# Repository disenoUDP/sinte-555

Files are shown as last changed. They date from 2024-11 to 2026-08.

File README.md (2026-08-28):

# sinte-555

proyecto inspirado en el chip 555 y el proyecto Atari Punk Console, en su iteración de Oskitone.

## acerca de

proyecto de investigación empezado en 2024, con el objetivo de crear un sintetizador de audio en diseño UDP.

## estructura del repositorio

* [openscad/](./openscad/): archivos de diseño de superficie en openscad
* [kicad/](./kicad/): archivos de diseño de circuito en KiCad

## código

### scripts de automatización

un aspecto muy bello de generar estructuras con STLs a partir de líneas de código, es que el diseño se puede parametrizar y automatizar.

## referencias

* Oskitone <https://oskitone.com>
* How to Create a Shell Script in linux <https://www.geeksforgeeks.org/how-to-create-a-shell-script-in-linux/>
* 555 timer circuits <https://www.555-timer-circuits.com/>

en este taller de 2 horas vamos a aprender a armar un sintetizador conocido como Atari Punk Console (APC).

## lista de materiales (bom)

| Nombre | Cantidad | $ unidad  | Enlace |
| :--- | :--- | :--- | :--- |
| Protoboard | 1 | 1.500 CLP | <https://afel.cl/products/mini-protoboard-400-puntos> |
| Chip 555 | 2 | 400 CLP | <https://www.mechatronicstore.cl/n555-timers/> |
| Potenciómetro 470k | 2 | 490 CLP | <https://www.mechatronicstore.cl/potenciometro-rotacional-10k/> |
| Resistor 10k | 2 | 100 CLP | <https://www.mechatronicstore.cl/resistencia/> |
| Capacitor 100n | 3 | 100 CLP | <https://www.mechatronicstore.cl/condensadores-ceramicos-distintos-valores/> |
| Capacitor 10n | 1 | 100 CLP | <https://www.mechatronicstore.cl/condensadores-ceramicos-distintos-valores/> |
| Parlante | 1 | 3.000 CLP | <https://afel.cl/products/mini-parlante-altavoz-de-3w> |

Algunas tiendas consultadas:

<https://www.mechatronicstore.cl/>
<https://www.victronics.cl/>
<https://www.cabezacuadrada.cl/>

## paso 01: ubicar los chips en la protoboard

tomar la protoboard y conectar los dos chips 555 en ella.

orientar los chips de manera que el pin 1 quede en la esquina inferior izquierda.

el izquierdo recibe el nombre 555-1, el derecho 555-2.

lo mismo con los potenciómetros: a la izquierda pote-1 y a la derecha  pote-2.

## paso 02: conectar la alimentación de los chips

conectar los pines de alimentación de los chips a los rieles de alimentación de la protoboard.

usar cables rojos para conectar al voltaje positivo.

usar cables negros o café para conectar al voltaje negativo (tierra).

## paso 03: armar el circuito de chip 555 de la izquierda, modo astable

patitas de 555-1:

* 1: a GND
* 2: a GND por C de 10n, a patita 3 de pote-1
* 3: a patita 2 de 555-2
* 4: a VCC
* 5: a GND por C de 100n
* 6: a patita 2
* 7: a VCC por R 10k, a patita 2 de pote-1
* 8: a VCC

patitas de pote-1:

* 1: nada
* 2: patita 7 de 555-1
* 3: patita 2 de 555-1

## paso 04: armar el circuito de 555 de la derecha, modo monostable

patitas de 555-2:

* 1: a GND
* 2: a patita 3 del chip 555-1
* 3: a patita 1 de parlante
* 4: a VCC
* 5: a GND por C de 100n
* 6: a patita 3 de pote-2 por R de 10k, a GND por C polarizado de 100n
* 7: a patita 6
* 8: a VCC

patitas de pote-2:

* 1: nada
* 2: a VCC
* 3: a patita 6 de 555-2 por R de 10k

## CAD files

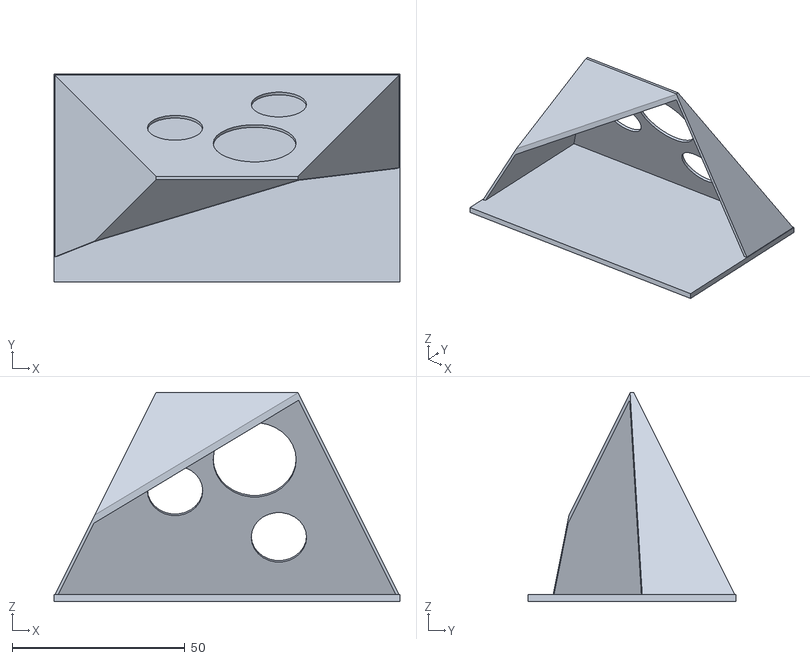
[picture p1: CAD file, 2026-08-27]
stl/piramidev20241211.stl
100.0 x 60.0 x 60.5

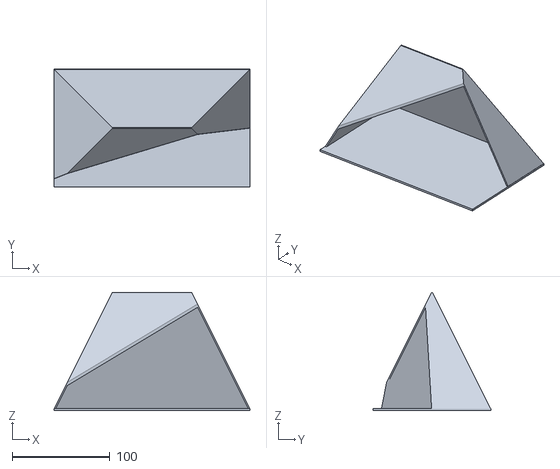
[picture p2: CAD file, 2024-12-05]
stl/piramidev3.stl
200.0 x 120.0 x 120.5

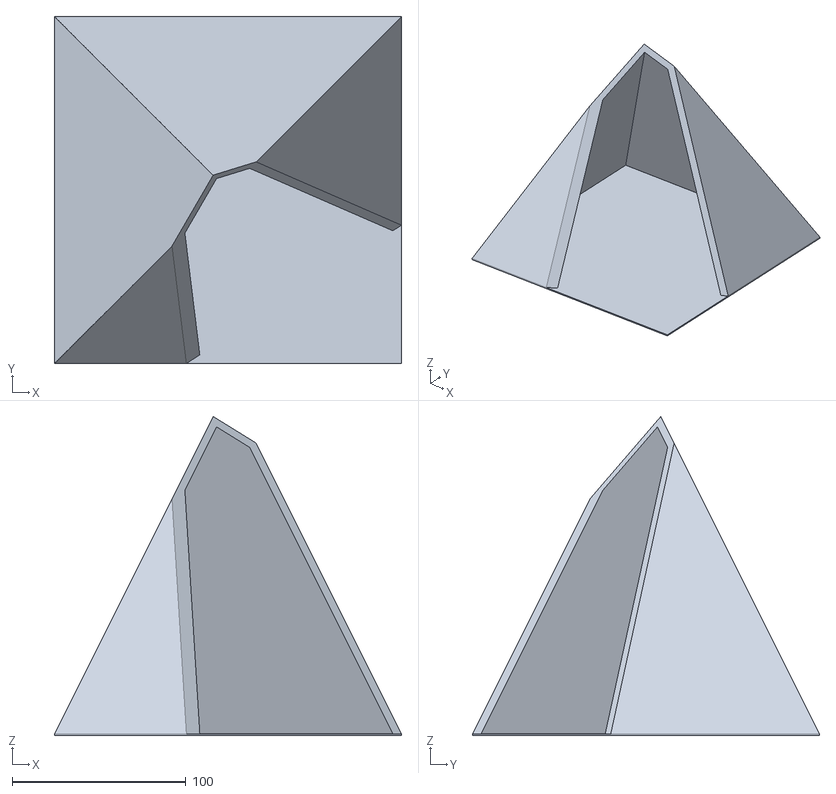
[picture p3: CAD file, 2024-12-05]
stl/piramidev1.stl
200.0 x 200.0 x 183.9

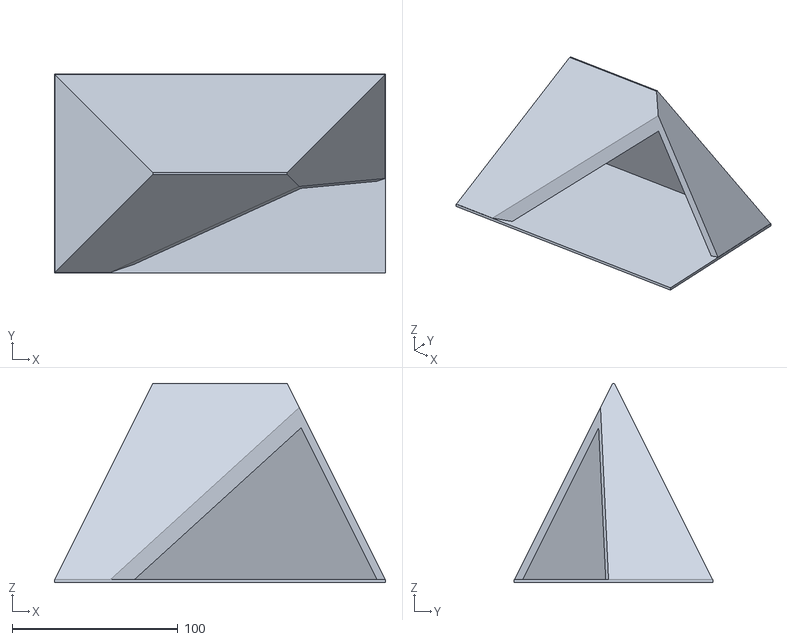
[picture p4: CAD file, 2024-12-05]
stl/piramidev2.stl
200.0 x 120.0 x 120.5

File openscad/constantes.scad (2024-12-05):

// lados exteriores
extLadoX = 53.0;
extLadoY = 82.0;
extLadoZ = 50.0;


// bordes de la caja
bordeX = 8.0;
bordeY = 8.0;
bordeZ = 8.0;


radioPerilla = 5.0;
radioParlante = 10;

radioEsferaFilete = 0;

// dimensiones protoboard en mm
protoBoardChicoX = 100;
protoBoardChicoY = 60;
protoBoardChicoZ = 30;

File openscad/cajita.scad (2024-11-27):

include <constantes.scad>;
include <creditos.scad>;


// resolucion = 5.0;
resolucion = 100.0;

module cajita(
    extLadoX,
    extLadoY,
    extLadoZ,
    bordeX,
    bordeY,
    bordeZ
    )
    
    {
    
    difference() {
    
    cube(
    [
    extLadoX,
    extLadoY,
    extLadoZ
    ],
    center = true);
    
    cube(
    [
    extLadoX - bordeX,
    extLadoY + bordeY,
    extLadoZ - bordeZ
    ],
    center = true);
    
    translate([15, -15, 20])
    cylinder (h = 20, r=radioPerilla, center = true, $fn = resolucion);
    
    translate([-15, -15, 20])
    cylinder (h = 20, r=radioPerilla, center = true, $fn = resolucion);
    
    translate([0, 20, 20])
    cylinder (h = 20, r=radioParlante, center = true, $fn = resolucion);
    
    color([1.0,0.0,1.0])
    translate([-extLadoX/2, -extLadoY/2, -extLadoZ/2])
    sphere(r=radioEsferaFilete);
    
    color([1.0,0.0,1.0])
    translate([-extLadoX/2, +extLadoY/2, -extLadoZ/2])
    sphere(r=radioEsferaFilete);
    
    color([1.0,0.0,1.0])
    translate([+extLadoX/2, -extLadoY/2, -extLadoZ/2])
    sphere(r=radioEsferaFilete);
    
    color([1.0,0.0,1.0])
    translate([+extLadoX/2, +extLadoY/2, -extLadoZ/2])
    sphere(r=radioEsferaFilete);
    
    color([1.0,0.0,1.0])
    translate([-extLadoX/2, -extLadoY/2, +extLadoZ/2])
    sphere(r=radioEsferaFilete);
    
    color([1.0,0.0,1.0])
    translate([-extLadoX/2, +extLadoY/2, +extLadoZ/2])
    sphere(r=radioEsferaFilete);
    
    color([1.0,0.0,1.0])
    translate([+extLadoX/2, -extLadoY/2, +extLadoZ/2])
    sphere(r=radioEsferaFilete);
    
    color([1.0,0.0,1.0])
    translate([+extLadoX/2, +extLadoY/2, +extLadoZ/2])
    sphere(r=radioEsferaFilete);

    }

    creditos();

};



cajita(
    extLadoX,
    extLadoY,
    extLadoZ,
    bordeX,
    bordeY,
    bordeZ
    );

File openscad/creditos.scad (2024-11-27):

module creditos() {
    color([1.0,0.0,1.0])
    rotate([0, 0, 180])
    translate([-25, 35, 25])
    linear_extrude(2)
    text("sinte555", size= 3, halign="left",valign = "baseline");

    color([1.0,0.0,1.0])
    rotate([0, 0, 180])
    translate([-25, 30, 25])
    linear_extrude(2)
    text("disenoUDP", size= 3, halign="left",valign = "baseline");

    color([1.0,0.0,1.0])
    rotate([0, 0, 180])
    translate([-25, 25, 25])
    linear_extrude(2)
    text("v0.0.1", size= 3, halign="left",valign = "baseline");
}

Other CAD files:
stl/piramidev4.stl
openscad/piramide.scad

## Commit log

2024-11-26 primera prueba con openscad, dos perillas y parlante
    [testing.scad, testing.stl]
2024-11-26 cambiar parametros
    [testing.scad]
2024-11-26 agregar borrador cajita
    [cajita.scad, testing.scad, testing.stl]
2024-11-27 reordenando archivos
    [cajita.scad, cajita.stl, constantes.scad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]
2024-11-27 agregar script de shell para automatizar crear STL
2024-11-28 borrar archivos
    [cajita.stl]
2024-12-05 agregar carpeta stl y parametros de protoboard chico
    [constantes.scad, piramide.scad, piramidev1.stl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]
2024-12-05 agregar parametros para angulo de corte
    [piramide.scad]
2024-12-11 agregar borrador kicad
2026-08-27 agregar kicad a .gitignore
2026-08-27 agregar stl antiguo
    [piramidev20241211.stl]
2026-08-27 agregar nueva version
    [sinte555.kicad_sch]
2026-08-27 mas ignore de kicad
2026-08-27 corregir valor
    [sinte555.kicad_sch]
2026-08-27 agregar bom
2026-08-28 agregar mas bom
2026-08-28 actualizar kicad_pro
